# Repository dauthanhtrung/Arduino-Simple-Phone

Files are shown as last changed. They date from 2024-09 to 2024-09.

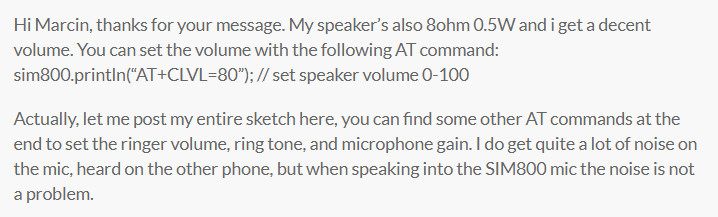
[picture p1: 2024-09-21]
DOCUMENT/79e526133139c4679d28.jpg

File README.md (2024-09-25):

# Arduino Simple Phone for Education

A mobile device capable of making calls and sending messages via the Arduino platform.

## Authors

- Facebook: [Đậu Thành Trung](https://www.facebook.com/dauthanhtrung.kma/)

- Email: dauthanhtrung.kma@gmail.com
## Demo
https://www.instructables.com/Arduino-Simple-Phone-for-Education/
## 🔗 Contact


## Screenshots

App Screenshot
App Screenshot
App Screenshot

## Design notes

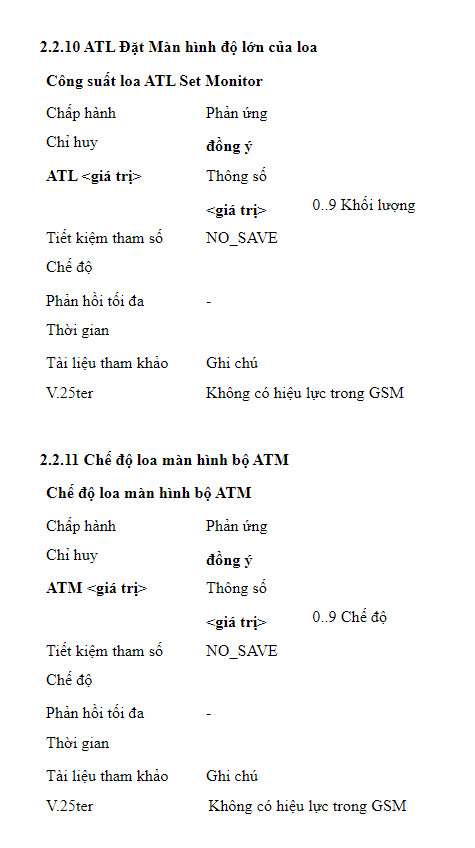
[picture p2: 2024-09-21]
DOCUMENT/1891669b77b182efdba0.jpg

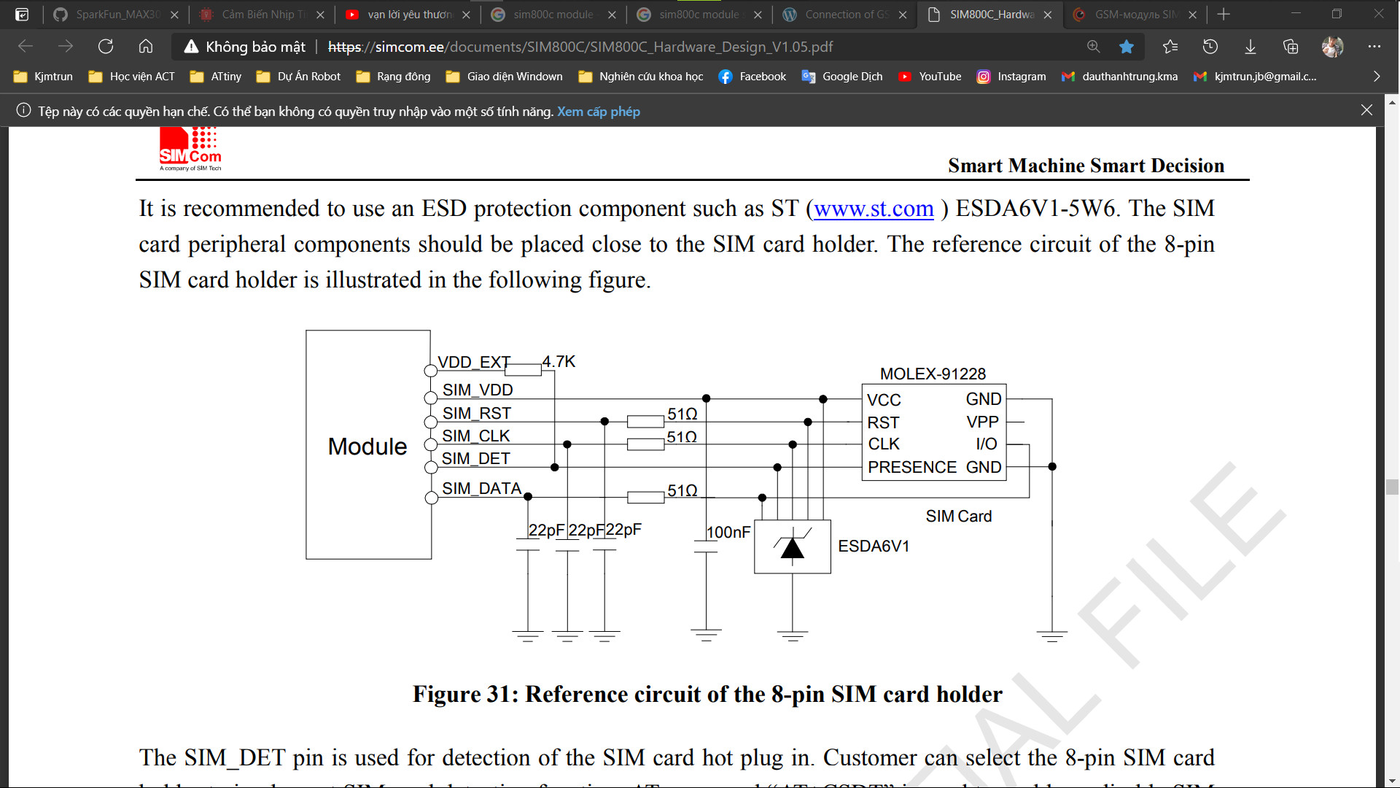
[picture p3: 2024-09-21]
DOCUMENT/d0e18e2aa135546b0d24.jpg

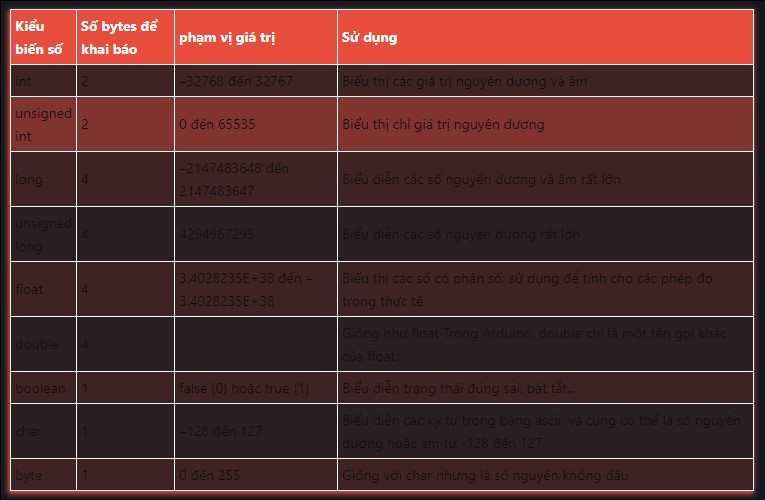
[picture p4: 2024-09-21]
DOCUMENT/KIỂU DỮ LIỆU.jpg

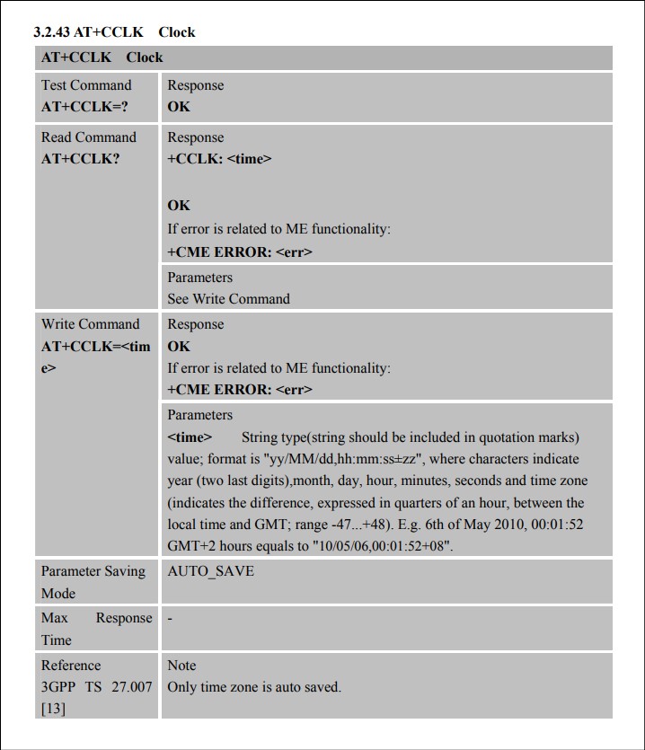
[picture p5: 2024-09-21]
DOCUMENT/Screenshot 2021-08-05 191245.jpg

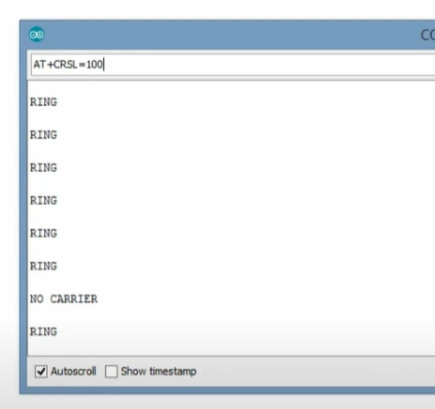
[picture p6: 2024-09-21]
DOCUMENT/7be02316343cc162982d.jpg

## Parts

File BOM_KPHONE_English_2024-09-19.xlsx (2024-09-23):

DANH SÁCH LINH KIỆN - BOMLIST
Bill of Materials for Project [KPHONE.PrjPcb] (No PCB Document Selected)
KMA ELECTRICAL |  |  | Project Name: | KPHONE.PrjPcb | Report Date: | 19/9/2024
 |  |  | Author: | Thành Trung |  | 01:40 PM
STT | Description | Comment | Footprint | Designator | Quantity | Note
1 | Antenna SMA | Antenna SMA | ANTEN SMA FEMALE | A2 | 1
2 | Button 2 pin | RESET | BUTTON-SMD-2P-3x6x2.5MM | B1 | 1
3 | Button 4 pin | Button | BUTTON-SMD-4P-6X6X5MM | B2, B3, B4, B5, B6, B7, B8, B9, B10, B11, B12, B13, B14, B15, B16, B17 | 16
4 | Buzzer | Buzzer | BUZZER_9055 | BZ1 | 1
5 | Capacitor SMD | 10uF/0805 | CAP-0805 | C1, C6, C17 | 3
6 | Capacitor SMD | 100nF/0603 | CAP-0603 | C2, C3, C4, C5, C8, C14 | 6
7 | Capacitor SMD | 0.1uF/0603 | CAP-0603 | C7, C18 | 2
8 | Capacitor SMD | 22uF/1206 | CAP-1206 | C9, C11 | 2
9 | Capacitor Pol Alumium SMD | 100uF/6.3X5.4 | CAPP-SMD-ALU-6.3X5.4MM-D | C10, C16 | 2
10 | Capacitor SMD | 22pF/0603 | CAP-0603 | C12, C13, C19, C20, C21, C22, C23, C24 | 8
11 | Capacitor SMD | 100nF | CAP-0603 | C15 | 1
12 | Diode Schottky | SS34 | DIODE-SMD-DO-214AC | D1 | 1
13 | USB 5P | USB | USB-FEMALE-MICRO-DIP | J1 | 1
14 | Header 2P | 2P | XH2.54-2P-R | J2 | 1
15 | Jump 4P | 4P | JUMP-2.54-MALE-4P-NB | J3, J4 | 2
16 | Socket Sim | Socket MicroSIM | SOCKET-MICRO-SIM-6P | J5 | 1
17 | Inductor SMD | 22uH/0603 | INDUCTOR-SMD-0630 | L1 | 1
18 | LCD Module Display Nokia 5110 SMD PCB | LCD NOKIA 5110 | LCD NOKIA 5110-SMD | LCD1 | 1
19 | Led SMD | BLUE/0603 | LED-0603-BLUE | LED1, LED4, LED6 | 3
20 | Led SMD | RED/0603 | LED-0603-RED | LED2, LED3, LED5 | 3
21 | Led SMD | WHITE/0603 | LED-0603-WHITE | LED7, LED8, LED9, LED10 | 4
22 | Led DIP | WHITE/5MM | LED-5MM-RED-R | LED11 | 1
23 | Module SIM800C PCB | SIM800C | SIM800C | M1 | 1
24 | Microphone MIC | Micro | MICRO-DIP-4.5X2.2-P2.0 | MIC1 | 1
25 | Transistor NPN | NPN | TRANSISTOR-SOT-23-BCE | Q1, Q2, Q3 | 3
26 | Resistor SMD | 100R | RES-0603 | R1 | 1
27 | Resistor SMD | 1K/0603 | RES-0603 | R2, R3, R4, R11, R17, R18, R29, R30, R31 | 9
28 | Resistor SMD | 1K2/0603 | RES-0603 | R5 | 1
29 | Resistor SMD | 0R/0805 | RES-0805 | R6, R7, R8, R13, R14 | 5
30 | Resistor SMD | 1K5/0603 | RES-0603 | R9 | 1
31 | Resistor SMD | 3K/0603 | RES-0603 | R10 | 1
32 | Resistor SMD | 4K7/0603 | RES-0603 | R12, R24 | 2
33 | Resistor SMD | NC | RES-0603 | R15 | 1
34 | Resistor SMD | 0R/0603 | RES-0603 | R16, R19, R20, R26 | 4
35 | Resistor SMD | 100R/0603 | RES-0603 | R21, R22, R23, R25, R27, R28 | 6
36 | Speaker | 4R/8W | SPEAKER 9X22MM | SPK1 | 1
37 | Switch SK-12D07 | Switch | SWITCH-3PIN-R | SW1 | 1
38 | IC DW01 SOT23-6 | DW01 | SOT-23-6 | U1 | 1
39 | IC TP4056 3.7V SOP-8 | TP4056 | TP4056 | U2 | 1
40 | IC FS8205A Dual N-Mosfet TSSOP-8 | FS8205A | FS8205A | U3 | 1
41 | IC ATmega328P IC MCU 8BIT 32KB FLASH 32P | ATmega328P | TQFP-32 | U4 | 1
42 | IC MT3608 DC-DC Converters 1.2MHz SOT-23-6 | MT3608 | SOT-23-6 | U5 | 1
43 | IC CH340C USB to TTL 2Mbps USB2.0 SOP-16 | CH340C | SOP-16 | U6 | 1
44 | Crystal 2P | 16MHz | CRYSTAL-SMD-5032-2P | X1 | 1

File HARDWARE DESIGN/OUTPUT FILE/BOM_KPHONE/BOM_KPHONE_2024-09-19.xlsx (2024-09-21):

DANH SÁCH LINH KIỆN - BOMLIST
Bill of Materials for Project [KPHONE.PrjPcb] (No PCB Document Selected)
KMA ELECTRICAL |  |  | Project Name: | KPHONE.PrjPcb | Report Date: | 19/9/2024
 |  |  | Author: | Thành Trung |  | 01:40 PM
STT | Description | Comment | Footprint | Designator | Quantity | Note
1 | Antenna SMA | Antenna SMA | ANTEN SMA FEMALE | A2 | 1
2 | Nút nhấn 2 chân | RESET | BUTTON-SMD-2P-3x6x2.5MM | B1 | 1
3 | Nút nhấn 4 chân | Button | BUTTON-SMD-4P-6X6X5MM | B2, B3, B4, B5, B6, B7, B8, B9, B10, B11, B12, B13, B14, B15, B16, B17 | 16
4 | Còi chip | Buzzer | BUZZER_9055 | BZ1 | 1
5 | Tụ dán | 10uF/0805 | CAP-0805 | C1, C6, C17 | 3
6 | Tụ dán | 100nF/0603 | CAP-0603 | C2, C3, C4, C5, C8, C14 | 6
7 | Tụ dán | 0.1uF/0603 | CAP-0603 | C7, C18 | 2
8 | Tụ dán | 22uF/1206 | CAP-1206 | C9, C11 | 2
9 | Tụ hoá dán | 100uF/6.3X5.4 | CAPP-SMD-ALU-6.3X5.4MM-D | C10, C16 | 2
10 | Tụ dán | 22pF/0603 | CAP-0603 | C12, C13, C19, C20, C21, C22, C23, C24 | 8
11 | Tụ dán | 100nF | CAP-0603 | C15 | 1
12 | Diode Schottky | SS34 | DIODE-SMD-DO-214AC | D1 | 1
13 | Cổng USB 5P | USB | USB-FEMALE-MICRO-DIP | J1 | 1
14 | Header 2P | 2P | XH2.54-2P-R | J2 | 1
15 | Jump 4P | 4P | JUMP-2.54-MALE-4P-NB | J3, J4 | 2
16 | Khe cắm Sim | Socket MicroSIM | SOCKET-MICRO-SIM-6P | J5 | 1
17 | Cuộn cảm dán | 22uH/0603 | INDUCTOR-SMD-0630 | L1 | 1
18 | LCD Module màn hình Nokia 5110 SMD PCB | LCD NOKIA 5110 | LCD NOKIA 5110-SMD | LCD1 | 1
19 | Led dán | BLUE/0603 | LED-0603-BLUE | LED1, LED4, LED6 | 3
20 | Led dán | RED/0603 | LED-0603-RED | LED2, LED3, LED5 | 3
21 | Led dán | WHITE/0603 | LED-0603-WHITE | LED7, LED8, LED9, LED10 | 4
22 | Led cắm | WHITE/5MM | LED-5MM-RED-R | LED11 | 1
23 | Module SIM800C hàn mạch PCB | SIM800C | SIM800C | M1 | 1
24 | Cảm biến âm thanh Microphone MIC | Micro | MICRO-DIP-4.5X2.2-P2.0 | MIC1 | 1
25 | Transistor NPN | NPN | TRANSISTOR-SOT-23-BCE | Q1, Q2, Q3 | 3
26 | Điện trở dán | 100R | RES-0603 | R1 | 1
27 | Điện trở dán | 1K/0603 | RES-0603 | R2, R3, R4, R11, R17, R18, R29, R30, R31 | 9
28 | Điện trở dán | 1K2/0603 | RES-0603 | R5 | 1
29 | Điện trở dán | 0R/0805 | RES-0805 | R6, R7, R8, R13, R14 | 5
30 | Điện trở dán | 1K5/0603 | RES-0603 | R9 | 1
31 | Điện trở dán | 3K/0603 | RES-0603 | R10 | 1
32 | Điện trở dán | 4K7/0603 | RES-0603 | R12, R24 | 2
33 | Điện trở dán | NC | RES-0603 | R15 | 1
34 | Điện trở dán | 0R/0603 | RES-0603 | R16, R19, R20, R26 | 4
35 | Điện trở dán | 100R/0603 | RES-0603 | R21, R22, R23, R25, R27, R28 | 6
36 | Loa | 4R/8W | SPEAKER 9X22MM | SPK1 | 1
37 | Công tắc gạt | Switch | SWITCH-3PIN-R | SW1 | 1
38 | IC DW01 Bảo vệ Pin SOT23-6 | DW01 | SOT-23-6 | U1 | 1
39 | IC TP4056 Quản lý sạc pin 3.7V SOP-8 | TP4056 | TP4056 | U2 | 1
40 | IC FS8205A Dual N-Mosfet TSSOP-8 | FS8205A | FS8205A | U3 | 1
41 | IC ATmega328P IC MCU 8BIT 32KB FLASH 32P | ATmega328P | TQFP-32 | U4 | 1
42 | IC MT3608 DC-DC Converters 1.2MHz SOT-23-6 | MT3608 | SOT-23-6 | U5 | 1
43 | IC CH340C Chuyển đổi USB to TTL 2Mbps USB2.0 SOP-16 | CH340C | SOP-16 | U6 | 1
44 | Thạch anh 2P | 16MHz | CRYSTAL-SMD-5032-2P | X1 | 1

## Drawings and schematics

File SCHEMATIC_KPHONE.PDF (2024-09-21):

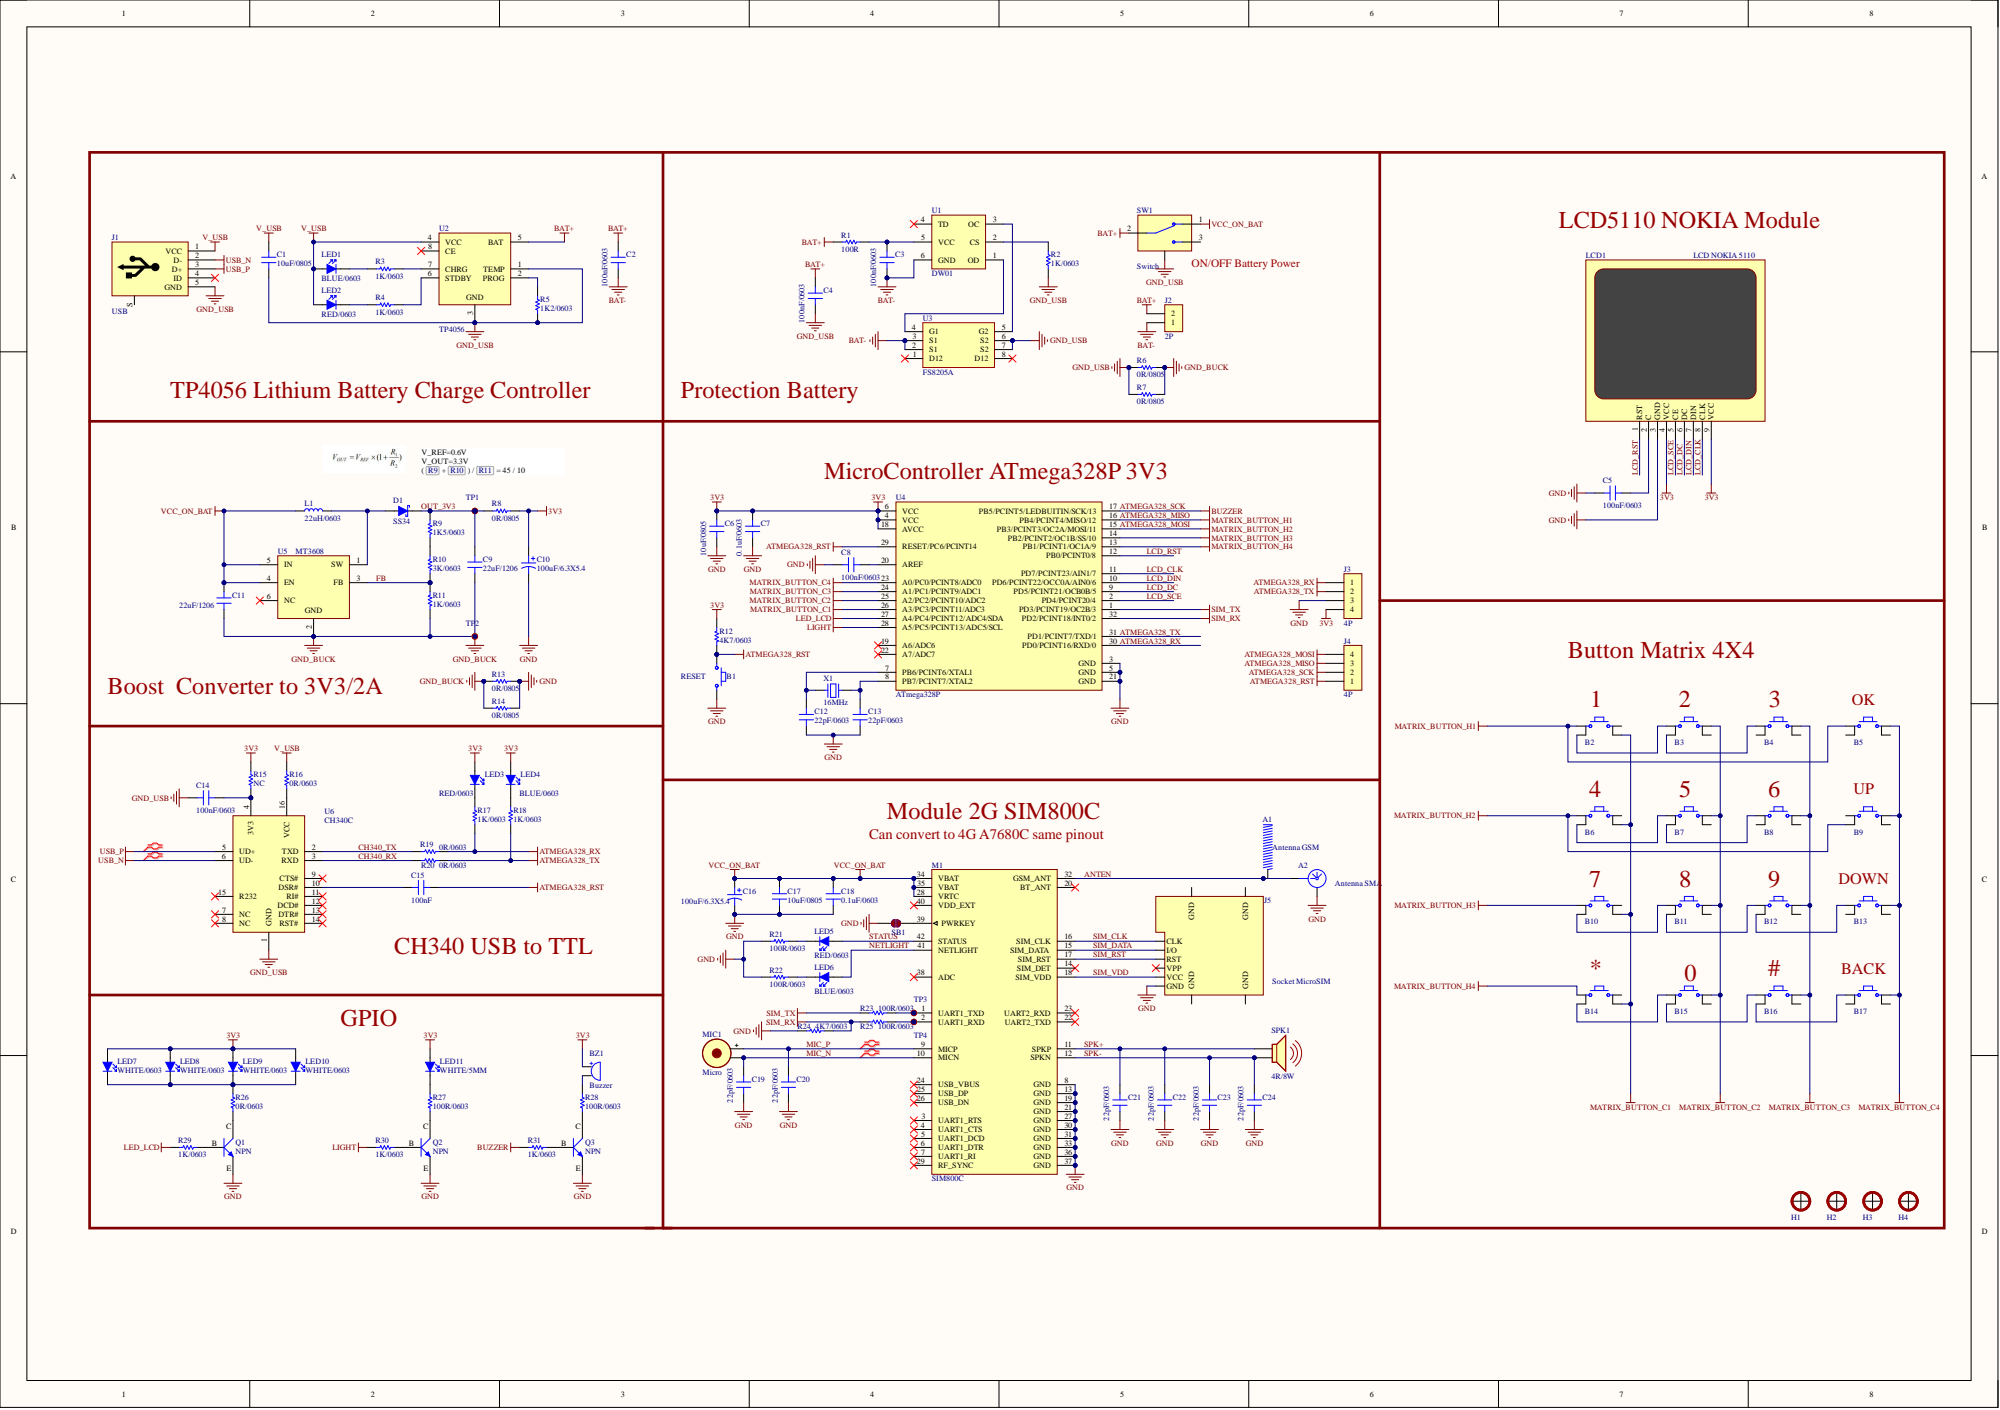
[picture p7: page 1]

ON/OFF Battery Power

Can convert to 4G A7680C same pinout

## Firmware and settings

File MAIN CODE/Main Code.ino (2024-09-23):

//****************************************//
//  Code by Dau Thanh Trung
//  Hoc Vien Ki Thuat Mat Ma
//  Phone: 0868242509
//  Gmail: dauthanhtrung.kma@gmail.com
//***************************************//
#include <SPI.h>
#include <Adafruit_GFX.h>
#include <Adafruit_PCD8544.h>	//Lcd Library
#include <String.h>
#include <SoftwareSerial.h>
#include <Keypad.h> 		//Keypad library
// #include <TimerOne.h>

//********************************************************************************************//

SoftwareSerial PHONE(3,2);// Connect with SIM module (Tx, Rx);
Adafruit_PCD8544 display = Adafruit_PCD8544(7, 6, 5, 4, 8); // LCD Nokia 5110 connect pin with Arduino
                                          //SCLK,DIN,DC,SCE,RST

// keyboard diagram
const byte ROWS = 4; 
const byte COLS = 4; 
char hexaKeys[ROWS][COLS] = {
  {'1', '2', '3', 'A'},
  {'4', '5', '6', 'B'},
  {'7', '8', '9', 'C'},
  {'*', '0', '#', 'D'}
};
/* A-OK; B-UP; C-DOWN; D-BACK*/

byte rowPins[ROWS] = {12, 11, 10, 9};  //Rows
byte colPins[COLS] = {A3, A2, A1, A0}; //Cols
Keypad key = Keypad(makeKeymap(hexaKeys), rowPins, colPins, ROWS, COLS); // Init Keypad

//********************************************************************************************//

boolean backlight = true;

unsigned char menu_item = 1;
unsigned char message_item = 1;
unsigned char page = 0;
int count=0;

//********************************************************************************************//
// Variables used
String number="";
String NUMBER=""; // number phone
String msg="";
String instr="";
String str_sms="";
String str_sms_2="";
String str_sms_3="";
String str1="";
String sms="";

String dd="";
String mm="";
String yy="";
String hh="";
String min="";
String time="";
String time_now="";


int ring=0;
int i=0,temp=0;
int sms_flag=0;
char sms_num[3];
int rec_read=0;
int temp1=0;

String ch="1,.?!@abc2def3ghi4jkl5mno6pqrs7tuv8wxyz90*# "; // Code for message

unsigned long real_time;  
unsigned char t=0;
unsigned char contrast=50;
char myKey;

//********************************************************************************************//
#define LIGHT A5	//Connect pin
#define BUZZER 13
#define LED_LCD A4


static const unsigned char PROGMEM tim[] = // Phone wave icon
{ 0x00,0x6C,0xFE,0xFE,0x7C,0x38,0x10,0x00};
// 'lock', 84x48px
const unsigned char LOCK [] PROGMEM = { // Lock icon
	0x00, 0x00, 0x00, 0x00, 0x00, 0x00, 0x00, 0x00, 0x00, 0x00, 0x00, 0x00, 0x00, 0x00, 0x00, 0x00, 
	0x00, 0x00, 0x00, 0x00, 0x00, 0x00, 0x00, 0x00, 0x00, 0x00, 0x00, 0x00, 0x00, 0x00, 0x00, 0x00, 
	0x00, 0x00, 0x00, 0x00, 0x00, 0x00, 0x00, 0x00, 0x00, 0x00, 0x00, 0x00, 0x00, 0x00, 0x00, 0x00, 
	0x00, 0x00, 0x00, 0x00, 0x00, 0x00, 0x00, 0x00, 0x00, 0x00, 0x00, 0x00, 0x00, 0x00, 0x00, 0x00, 
	0x00, 0x00, 0x00, 0x00, 0x00, 0x00, 0x07, 0xc0, 0x00, 0x00, 0x00, 0x00, 0x00, 0x00, 0x00, 0x00, 
	0x00, 0x1f, 0xf0, 0x00, 0x00, 0x00, 0x00, 0x00, 0x00, 0x00, 0x00, 0x00, 0x3f, 0xfc, 0x00, 0x00, 
	0x00, 0x00, 0x00, 0x00, 0x00, 0x00, 0x00, 0x7f, 0xfe, 0x00, 0x00, 0x00, 0x00, 0x00, 0x00, 0x00, 
	0x00, 0x00, 0xf8, 0x3e, 0x00, 0x00, 0x00, 0x00, 0x00, 0x00, 0x00, 0x00, 0x01, 0xf0, 0x0f, 0x00, 
	0x00, 0x00, 0x00, 0x00, 0x00, 0x00, 0x00, 0x01, 0xe0, 0x07, 0x80, 0x00, 0x00, 0x00, 0x00, 0x00, 
	0x00, 0x00, 0x03, 0xc0, 0x07, 0x80, 0x00, 0x00, 0x00, 0x00, 0x00, 0x00, 0x00, 0x03, 0xc0, 0x03, 
	0x80, 0x00, 0x00, 0x00, 0x00, 0x00, 0x00, 0x00, 0x03, 0x80, 0x03, 0x80, 0x00, 0x00, 0x00, 0x00, 
	0x00, 0x00, 0x00, 0x03, 0x80, 0x03, 0xc0, 0x00, 0x00, 0x00, 0x00, 0x00, 0x00, 0x00, 0x03, 0x80, 
	0x03, 0xc0, 0x00, 0x00, 0x00, 0x00, 0x00, 0x00, 0x00, 0x03, 0x80, 0x03, 0xc0, 0x00, 0x00, 0x00, 
	0x00, 0x00, 0x00, 0x00, 0x03, 0x80, 0x03, 0xc0, 0x00, 0x00, 0x00, 0x00, 0x00, 0x00, 0x00, 0x0f, 
	0xff, 0xff, 0xe0, 0x00, 0x00, 0x00, 0x00, 0x00, 0x00, 0x00, 0x1f, 0xff, 0xff, 0xf0, 0x00, 0x00, 
	0x00, 0x00, 0x00, 0x00, 0x00, 0x1f, 0xff, 0xff, 0xf0, 0x00, 0x00, 0x00, 0x00, 0x00, 0x00, 0x00, 
	0x1f, 0xff, 0xff, 0xf0, 0x00, 0x00, 0x00, 0x00, 0x00, 0x00, 0x00, 0x1f, 0xfc, 0x7f, 0xf0, 0x00, 
	0x00, 0x00, 0x00, 0x00, 0x00, 0x00, 0x1f, 0xf8, 0x3f, 0xf0, 0x00, 0x00, 0x00, 0x00, 0x00, 0x00, 
	0x00, 0x1f, 0xf0, 0x1f, 0xf0, 0x00, 0x00, 0x00, 0x00, 0x00, 0x00, 0x00, 0x1f, 0xf0, 0x1f, 0xf0, 
	0x00, 0x00, 0x00, 0x00, 0x00, 0x00, 0x00, 0x1f, 0xf0, 0x1f, 0xf0, 0x00, 0x00, 0x00, 0x00, 0x00, 
	0x00, 0x00, 0x1f, 0xf8, 0x1f, 0xf0, 0x00, 0x00, 0x00, 0x00, 0x00, 0x00, 0x00, 0x1f, 0xf8, 0x3f, 
	0xf0, 0x00, 0x00, 0x00, 0x00, 0x00, 0x00, 0x00, 0x1f, 0xfc, 0x7f, 0xf0, 0x00, 0x00, 0x00, 0x00, 
	0x00, 0x00, 0x00, 0x1f, 0xfc, 0x3f, 0xf0, 0x00, 0x00, 0x00, 0x00, 0x00, 0x00, 0x00, 0x1f, 0xf8, 
	0x3f, 0xf0, 0x00, 0x00, 0x00, 0x00, 0x00, 0x00, 0x00, 0x1f, 0xf8, 0x3f, 0xf0, 0x00, 0x00, 0x00, 
	0x00, 0x00, 0x00, 0x00, 0x1f, 0xf8, 0x3f, 0xf0, 0x00, 0x00, 0x00, 0x00, 0x00, 0x00, 0x00, 0x1f, 
	0xf8, 0x1f, 0xf0, 0x00, 0x00, 0x00, 0x00, 0x00, 0x00, 0x00, 0x1f, 0xf0, 0x1f, 0xf0, 0x00, 0x00, 
	0x00, 0x00, 0x00, 0x00, 0x00, 0x1f, 0xff, 0xff, 0xf0, 0x00, 0x00, 0x00, 0x00, 0x00, 0x00, 0x00, 
	0x1f, 0xff, 0xff, 0xf0, 0x00, 0x00, 0x00, 0x00, 0x00, 0x00, 0x00, 0x0f, 0xff, 0xff, 0xf0, 0x00, 
	0x00, 0x00, 0x00, 0x00, 0x00, 0x00, 0x0f, 0xff, 0xff, 0xe0, 0x00, 0x00, 0x00, 0x00, 0x00, 0x00, 
	0x00, 0x00, 0x00, 0x00, 0x00, 0x00, 0x00, 0x00, 0x00, 0x00, 0x00, 0x00, 0x00, 0x00, 0x00, 0x00, 
	0x00, 0x00, 0x00, 0x00, 0x00, 0x00, 0x00, 0x00, 0x00, 0x00, 0x00, 0x00, 0x00, 0x00, 0x00, 0x00, 
	0x00, 0x00, 0x00, 0x00, 0x00, 0x00, 0x00, 0x00, 0x00, 0x00, 0x00, 0x00, 0x00, 0x00, 0x00, 0x00, 
	0x00, 0x00, 0x00, 0x00, 0x00, 0x00, 0x00, 0x00, 0x00, 0x00, 0x00, 0x00, 0x00, 0x00, 0x00, 0x00
};


static const unsigned char PROGMEM viettel[] = // Network provider icon
{ B00000000, B00000000,
  B00000000, B00000000,
  B00000001, B00000000,
  B00000101, B00000000,
  B00010101, B00000000,
  B01010101, B00000000,
  B01010101, B00000000,
  B01010101, B00000000,
  B00000000, B00000000,
  B00000000, B00000000,
  B00000000, B00000000,
  B00000000, B00000000,
  B00000000, B00000000,
  B00000000, B00000000,
  B00000000, B00000000,
  B00000000, B00000000 };
static const unsigned char PROGMEM battery_icon[] =  // Battery icon
{ B00000000, B00000000,
  B01111111, B11000000,
  B01000000, B01000000,
  B11010101, B01000000,
  B11010101, B01000000,
  B11010101, B01000000,
  B01000000, B01000000,
  B01111111, B11000000,
  B00000000, B00000000,
  B00000000, B00000000,
  B00000000, B00000000,
  B00000000, B00000000,
  B00000000, B00000000,
  B00000000, B00000000,
  B00000000, B00000000,
  B00000000, B00000000 };

static const unsigned char PROGMEM message_icon[] =  // Message icon
{ B11111111, B11111000,
  B10100000, B00101000,
  B10010000, B01001000,
  B10001000, B10001000,
  B10000101, B00001000,
  B10000010, B00001000,
  B10000000, B00001000,
  B11111111, B11111000,
  B00000000, B00000000,
  B00000000, B00000000,
  B00000000, B00000000,
  B00000000, B00000000,
  B00000000, B00000000,
  B00000000, B00000000,
  B00000000, B00000000,
  B00000000, B00000000 };

void setup() {
  pinMode(LED_LCD,OUTPUT);  //Backlight for LCD
  pinMode(LIGHT,OUTPUT);    //Light
  pinMode(BUZZER,OUTPUT);   //Buzzer

  digitalWrite(LED_LCD,LOW);
  digitalWrite(LIGHT,LOW);
  digitalWrite(BUZZER,LOW);
  // Timer1.initialize(1000000); //Init interrupt
  // Timer1.attachInterrupt(GetTime);
  real_time = millis();
  // Serial.begin(9600);
  //Init LCD
  display.begin();      
  // display.setContrast(50); //Set contrast to 50
  display.setContrast(contrast);
  display.display();
  display.clearDisplay(); 
  display.display(); 
  //Init SIM module
  PHONE.begin(9600);
  gsm_init();
  
  // delay(2000);
}

void loop() { //Main program
  if( (millis() - real_time) >10000 ){ // get time from network
    real_time = millis();
    GetTime();
  }
  serialEvent(); // Check message and calling
  myKey = key.getKey();//Check button keypad
  drawMenu(); // Main Home
  
  // Handling incoming call and message events
  if(ring == 1){ // Incoming call detected
    while(ring==1)
    {
     
      page_7();
      ring=0;
      GetTime();
      // page=0;
      // break;
    }
    instr=""; i=0;// reset state
    GetTime();
    delay(500);
  }
  //*****************************Get message********************************//
  // if(sms_flag==1){
  //   while(sms_flag==1)
  //   {
  //     display.clearDisplay();
  //     str_sms=instr;
  //     int loc=instr.indexOf("+CMT: \"");
  //     number=instr.substring(loc+7,loc+19); // Split phone number

  //     int L1=str_sms.indexOf("+CMT: \"");
  //     int L2 = str_sms.length();
  //     str_sms_2=str_sms.substring(L1,L2); // Split content

  //     int L3=str_sms_2.indexOf("\"\r\n");
  //     int L4=str_sms_2.length();
  //     str_sms_3=str_sms_2.substring(L3+3,L4); // Extract message content
  //     String sms = str_sms_3; 
  //     display.setCursor(0,10);
  //     display.print(number); // Get phone number
  //     display.setCursor(0,20);
  //     display.print("<");
  //     display.print(str_sms_3); // New message
  //     display.print("Noi dung: "); // New message
  //     display.print(">");
  //     display.display();
  //     delay(5000);
  //     page_9();
  //     // instr=""; // Reset state
  //     str_sms="";
  //     str_sms_2="";
  //     str_sms_3="";
  //     sms="";number="";
  //     sms_flag=0;
  //     page=0;
  //     GetTime();
  //   }
  //   delay(200);
    
  // }
 

  //Lock screen by button '0'
  if (myKey=='0')
  {
    if (page == 0){
      page=99;
    }
    else if (page == 99){
      page=0;
    }
  }
  // Change menu and variable
  //Button OK
  if (myKey=='A')
  {
    if (page == 1 && menu_item==3) 
    {
      if (backlight) 
      {
        backlight = false;
        digitalWrite(LIGHT,HIGH);
      }
      else 
      {
        backlight = true; 
        digitalWrite(LIGHT,LOW);
        
      }
    }

    if(page == 1 && menu_item ==2)
    {
      page=3;
    }
    else if (page == 1 && menu_item==1)
    {
      page=2;
    }
    else if (page == 0 )
    {
      page=1;
    }
    else if (page == 8 && temp1 == 1 )
    {
      DocTinNhan();
    }
    else if (page == 4 && message_item )
    {
      page_5();
    }
  }
  //Button up
  if (myKey=='B')
  {
    if (page == 0){
      contrast++;
      if(contrast>50) contrast=25;
      display.setContrast(contrast);
      display.display();
    }
    else if (page == 1 ) 
    {
      menu_item--;
      if (menu_item==0) menu_item=3;
    }
    else if(page ==3)
    {
      temp++;
    }
    else if(page == 4 ) 
    {
      message_item--;
      if (message_item==0) message_item=3;
    }
  }

//Button down
  if (myKey=='C')
  {
    if (page == 0){
      contrast--;
      if(contrast<25) contrast=50;
      display.setContrast(contrast);
      display.display();
    }
    else if (page == 1)
    {
      menu_item++;
      if (menu_item==4) menu_item=1;      
    }
    else if(page ==3)
    {
      temp--;
    }
    else if(page == 4 )
    {
      message_item++;
      if (message_item==4) message_item=1;
    }
  }
  

   //Button Back
   if (myKey=='D') //BACK
   { 
    if (page == 1 )
    {
      page=0;
    }
    else if (page == 2) 
    {
      page=1;
     }

    else if (page == 4) 
    {
      page=3;
    }
    else if (page == 0) 
    {
      page=8;
    }
    else if (page == 8) 
    {
      page=0;
    }

   }
   
}
void NhapSDT()
{
  count=0;
  NUMBER="";
  while(1) // true
  {
    char myKey = key.getKey();
    display.setTextSize(1);
    display.setTextColor(BLACK, WHITE);

    if(myKey=='1')
    {
      display.setCursor((count*6)+12, 25);
      display.print(myKey);
      NUMBER+=myKey;
      count++;
    }
    if(myKey=='2')
    {
      display.setCursor((count*6)+12, 25);
      display.print(myKey);
      NUMBER+=myKey;
      count++;
    }
    if(myKey=='3')
    {
      display.setCursor((count*6)+12, 25);
      display.print(myKey);
      NUMBER+=myKey;
      count++;
    }
    if(myKey=='4')
    {
      display.setCursor((count*6)+12, 25);
      display.print(myKey);
      NUMBER+=myKey;
      count++;
    }
    if(myKey=='5')
    {
      display.setCursor((count*6)+12, 25);
      display.print(myKey);
      NUMBER+=myKey;
      count++;
    }
    if(myKey=='6')
    {
      display.setCursor((count*6)+12, 25);
      display.print(myKey);
      NUMBER+=myKey;
      count++;
    }
    if(myKey=='7')
    {
      display.setCursor((count*6)+12, 25);
      display.print(myKey);
      NUMBER+=myKey;
      count++;
    }
    if(myKey=='8')
    {
      display.setCursor((count*6)+12, 25);
      display.print(myKey);
      NUMBER+=myKey;
      count++;
    }
    if(myKey=='9')
    {
      display.setCursor((count*6)+12, 25);
      display.print(myKey);
      NUMBER+=myKey;
      count++;
    }
    if(myKey=='0')
    {
      display.setCursor((count*6)+12, 25);
      display.print(myKey);
      NUMBER+=myKey;
      count++;
    }

    if(myKey=='A' && page == 2)// call button handle
    {
      NUMBER.remove(0,1);
      // Call command here
      PHONE.print("ATD+ +84"); // change your country code here
      PHONE.print(NUMBER);
      PHONE.println(";");
      delay(100);
      //******************************//
      page=6; // calling
      break;
    }
    if(myKey=='A' && page == 3)// handle send message button
    {
      NUMBER.remove(0,1);
      page=4; // choose message
      break;
    }
     
    if(myKey=='D') // button Delete and back
     {
        count--;
        NUMBER.remove(count);
        display.setCursor((count*6)+12, 25);
        display.print(" ");
     }
    if(myKey=='D' && count<0)
     {
       page=1;
       count=0;
       break;
     }
    if(count==0)
    {
        display.setCursor(58, 40);
        display.print("BACK");
    }
    else 
    {
        display.setCursor(58, 40);
        display.print("XOA ");
    }
    display.display();
  }
}
//********************Enter message to send***********************//
void NhapTinNhan()
{
  int x=0,y=0,num=0;
  msg="";
  while(1)
  {
    char myKey=key.getKey();
      // Enter data
       if(myKey=='1')
       {
         num=0;
         display.setCursor(x*6,(y*10)+10);
         display.print(ch[num]);
         display.display();
         for(int i=0;i<30000;i++)
         { 
          char myKey=key.getKey();
          if(myKey=='1')
          {
           num++;
           if(num>5)
           num=0;
           display.setCursor(x*6,(y*10)+10);
           display.print(ch[num]);
           display.display();
           i=0;
           delay(20);
          } 
         }
         x++;
         if(x>13)
         {
           x=0;
           y++;
           y%=3;
         }
         msg+=ch[num];
        }

       else if(myKey=='2')
       {
         num=6;
         display.setCursor(x*6,(y*10)+10);
         display.print(ch[num]);
         display.display();
         for(int i=0;i<30000;i++)
         { 
          char myKey=key.getKey();
          if(myKey=='2')
          {
           num++;
           if(num>9)
           num=6;
           display.setCursor(x*6,(y*10)+10);
           display.print(ch[num]);
           display.display();
           i=0;
           delay(20);
          } 
         }
         x++;
         if(x>13)
         {
           x=0;
           y++;
           y%=3;
         }
         msg+=ch[num];
        }

       else if(myKey=='3')
       {
         num=10;
         display.setCursor(x*6,(y*10)+10);
         display.print(ch[num]);
         display.display();
         for(int i=0;i<30000;i++)
         { 
          char myKey=key.getKey();
          if(myKey=='3')
          {
           num++;
           if(num>13)
           num=10;
           display.setCursor(x*6,(y*10)+10);
           display.print(ch[num]);
           display.display();
           i=0;
           delay(20);
          } 
         }
         x++;
         if(x>13)
         {
           x=0;
           y++;
           y%=3;
         }
         msg+=ch[num];
        }

       else if(myKey=='4')
       {
         num=14;
         display.setCursor(x*6,(y*10)+10);
         display.print(ch[num]);
         display.display();
         for(int i=0;i<30000;i++)
         { 
          char myKey=key.getKey();
          if(myKey=='4')
          {
           num++;
           if(num>17)
           num=14;
           display.setCursor(x*6,(y*10)+10);
           display.print(ch[num]);
           display.display();
           i=0;
           delay(20);
          } 
         }
         x++;
         if(x>13)
         {
           x=0;
           y++;
           y%=3;
         }
         msg+=ch[num];
        }

      else if(myKey=='5')
       {
         num=18;
         display.setCursor(x*6,(y*10)+10);
         display.print(ch[num]);
         display.display();
         for(int i=0;i<30000;i++)
         { 
          char myKey=key.getKey();
          if(myKey=='5')
          {
           num++;
           if(num>21)
           num=18;
           display.setCursor(x*6,(y*10)+10);
           display.print(ch[num]);
           display.display();
           i=0;
           delay(20);
          } 
         }
         x++;
         if(x>13)
         {
           x=0;
           y++;
           y%=3;
         }
         msg+=ch[num];
        }

        else if(myKey=='6')
       {
         num=22;
         display.setCursor(x*6,(y*10)+10);
         display.print(ch[num]);
         display.display();
         for(int i=0;i<30000;i++)
         { 
          char myKey=key.getKey();
          if(myKey=='6')
          {
           num++;
           if(num>25)
           num=22;
           display.setCursor(x*6,(y*10)+10);
           display.print(ch[num]);
           display.display();
           i=0;
           delay(20);
          } 
         }
         x++;
         if(x>13)
         {
           x=0;
           y++;
           y%=3;
         }
         msg+=ch[num];
        }

       else if(myKey=='7')
       {
         num=26;
         display.setCursor(x*6,(y*10)+10);
         display.print(ch[num]);
         display.display();
         for(int i=0;i<30000;i++)
         { 
          char myKey=key.getKey();
          if(myKey=='7')
          {
           num++;
           if(num>30)
           num=26;
           display.setCursor(x*6,(y*10)+10);
           display.print(ch[num]);
           display.display();
           i=0;
           delay(20);
          } 
         }
         x++;
         if(x>13)
         {
           x=0;
           y++;
           y%=3;
         }
         msg+=ch[num];
        }

       else if(myKey=='8')
       {
         num=31;
         display.setCursor(x*6,(y*10)+10);
         display.print(ch[num]);
         display.display();
         for(int i=0;i<30000;i++)
         { 
          char myKey=key.getKey();
          if(myKey=='8')
          {
           num++;
           if(num>34)
           num=31;
           display.setCursor(x*6,(y*10)+10);
           display.print(ch[num]);
           display.display();
           i=0;
           delay(20);
          } 
         }
         x++;
         if(x>13)
         {
           x=0;
           y++;
           y%=3;
         }
         msg+=ch[num];
        }

       else if(myKey=='9')
       {
         num=35;
         display.setCursor(x*6,(y*10)+10);
         display.print(ch[num]);
         display.display();
         for(int i=0;i<30000;i++)
         { 
          char myKey=key.getKey();
          if(myKey=='9')
          {
           num++;
           if(num>39)
           num=35;
           display.setCursor(x*6,(y*10)+10);
           display.print(ch[num]);
           display.display();
           i=0;
           delay(20);
          } 
         }
         x++;
         if(x>13)
         {
           x=0;
           y++;
           y%=3;
         }
         msg+=ch[num];
        }

        else if(myKey=='0')
       {
         num=40;
         display.setCursor(x*6,(y*10)+10);
         display.print(ch[num]);
         display.display();
         for(int i=0;i<30000;i++)
         { 
          char myKey=key.getKey();
          if(myKey=='0')
          {
           num++;
           if(num>41)
           num=40;
           display.setCursor(x*6,(y*10)+10);
           display.print(ch[num]);
           display.display();
           i=0;
           delay(20);
          } 
         }
         x++;
         if(x>13)
         {
           x=0;
           y++;
           y%=3;
         }
         msg+=ch[num];
        }

        // Function button
        else if(myKey=='D')
        {
          x--;msg.remove(x);
          if(x<0 && y>0){
            x=13;
            y--;
          }
          if(x<0 && y==0) {
            page=3;
            break;
          }
          
          display.setCursor(x*6,(y*10)+10);
          display.print(" ");
          display.display();
        } 
        else if(myKey=='A')
        {
         // Serial.println("Gửi");
          page=5;
          break;
        } 
        else if(x==0 && y==0){
            display.setCursor(58, 40);
            display.print("BACK");
            display.display();
          }
        else if(x>0 && y>=0){
            display.setCursor(58, 40);
            display.print(" XOA");
            display.display();
          }
    }
}
//***********************Read Incoming Messages********************//
void DocTinNhan()
{
  display.clearDisplay();
  display.setCursor(0,0);
  display.print(number);
  display.setCursor(0,10);
  display.print("Please wait...");
  display.display();
  delay(2000);
  // PHONE.print("AT+CMGR=");
  // PHONE.println(sms_num);
  // PHONE.print("AT+CMGR=1<CR><LF>");delay(100); //Save message to memory

  // str_sms="Dau Thanh Trung";
  // int l1=str_sms.indexOf("\"\r\n");
  // int l2=str_sms.indexOf("OK");

  // String sms=str_sms.substring(l1+3,l2-4);

  // display.clearDisplay();
  // display.print(sms);
  display.setCursor(58, 40);
  display.print("BACK");
  display.display();
  delay(5000);
}
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

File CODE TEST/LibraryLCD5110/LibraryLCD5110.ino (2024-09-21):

#include <Adafruit_GFX.h>
#include <Adafruit_PCD8544.h>
#include <SPI.h>


Adafruit_PCD8544 display = Adafruit_PCD8544(7, 6, 5, 4, 8);

// Hardware SPI (faster, but must use certain hardware pins):
// SCK is LCD serial clock (SCLK) - this is pin 13 on Arduino Uno
// MOSI is LCD DIN - this is pin 11 on an Arduino Uno
// pin 5 - Data/Command select (D/C)
// pin 4 - LCD chip select (CS)
// pin 3 - LCD reset (RST)
// Adafruit_PCD8544 display = Adafruit_PCD8544(5, 4, 3);
// Note with hardware SPI MISO and SS pins aren't used but will still be read
// and written to during SPI transfer.  Be careful sharing these pins!


static const unsigned char PROGMEM trun[] =
{ B00000000, B00000000,
  B00000000, B00000000,
  B00000000, B00000000,
  B00000000, B00000000,
  B00001100, B01100000,
  B00011110, B11110000,
  B00011111, B11110000,
  B00011111, B11110000,
  B00001111, B11100000,
  B00000111, B11000000,
  B00000011, B10000000,
  B00000001, B00000000,
  B00000000, B00000000,
  B00000000, B00000000,
  B00000000, B00000000,
  B00000000, B00000000 };
static const unsigned char PROGMEM viettel[] =
{ B00000000, B00000000,
  B00000000, B00000000,
  B00000001, B00000000,
  B00000101, B00000000,
  B00010101, B00000000,
  B01010101, B00000000,
  B01010101, B00000000,
  B01010101, B00000000,
  B00000000, B00000000,
  B00000000, B00000000,
  B00000000, B00000000,
  B00000000, B00000000,
  B00000000, B00000000,
  B00000000, B00000000,
  B00000000, B00000000,
  B00000000, B00000000 };


void setup()   {
  Serial.begin(9600);
  display.begin();// KHỞI TẠO
  display.clearDisplay();
  display.setContrast(50); // ĐỘ TƯƠNG PHẢN
  // logo();
  // delay(500);
  display.clearDisplay();
     //display.invertDisplay(true); // đảo ngược màn hình?

}
void logo(){
      display.drawBitmap(5, 5,  trun, 16, 16, 1); // vẽ logo
      display.display();
 
}
int i=0,h,w;
void loop(){
  w= display.width();   //lấy chiều rộng
  h= display.height();  //lấy chiều cao màn hình
  display.clearDisplay();     // xóa màn hình
  // display.fillRect(0, 0, 83, 47, BLACK); // vẽ nền đen
  // display.setRotation(1);     // xoay 90 độ, chọn 1,2,3
  display.setTextSize(1);     // đặt kích cỡ
  display.setTextColor(WHITE);//chọn màu chữ BLACK hoặc WHITE
  display.setCursor(28,1);     //chọn vị trí
 display.println("MENU");//in kí tự ra màn hình

  // display.setCursor(27,10);     //chọn vị trí
  // display.println(i);//in kí tự ra màn hình
  display.drawFastHLine(0,10,83,BLACK); // vẽ nhanh đường thẳng
  //Màn hình kích thước 84x48. Nhưng bắt đầu từ 0 nên 84-1 x 48-1 ~ 83x47
  // display.drawLine(0, 0, 83, 0, BLACK); //vẽ đường (x1,y1,x2,y2,BLACK). Trong tọa độ O(x,y): x- chiều rộng=83, y- chiều cao =47
  // display.drawLine(0, 0, 0, 47, BLACK);
  // display.drawLine(0, 47, 83, 47, BLACK);
  // display.drawLine(83, 0, 83, 47, BLACK);

  // display.drawLine(3, 3, 80, 3, WHITE); //vẽ đường (x1,y1,x2,y2,WHITE). Trong tọa độ O(x,y): x- chiều rộng=80, y- chiều cao =47
  // display.drawLine(3, 3, 3, 44, WHITE);
  // display.drawLine(3, 44, 80, 44, WHITE);
  // display.drawLine(80, 3, 80, 44, WHITE);

  // display.drawTriangle(display.width()/2, display.height()/2-i,
  //                    display.width()/2-i, display.height()/2+i,
  //                    display.width()/2+i, display.height()/2+i, WHITE); //Vẽ hình tam giác: tọa độ (đỉnh, đỉnh trái, đỉnh phải,WHITE);
  /*
  Hàm vẽ hình: display.draw + hình: Rect, Circle, Triangle (Vuông, tròn, tam giác)
  Đổ màu vào hình. display.fill+ hình.(Tọa độ):
  Hình vuông: lấy tọa độ đường chéo. (x1, y1, w, h, BLACK)
        //display.drawRect(65,20,4,4,BLACK);//(Tọa độ x,y, kích thước 4x4, BLACK);
  Hình tròn: lấy tọa độ tâm. và bán kính R. (x1, y1, R, BLACK)
  Hình tam giác: lấy tọa độ 3 đỉnh. (x1, y1, x2, y2, x3, y3, BLACK)
  
  */

   display.drawRoundRect(0, 0, 83, 47, 10, BLACK);// vẽ hình bo góc (tọa độ đầu, chiều rộng, chiều dài, bo góc,BLACK)
  // display.fillTriangle(display.width()/2, display.height()/2-i,
  //                    display.width()/2-i, display.height()/2+i,
  //                    display.width()/2+i, display.height()/2+i, WHITE);

  // display.fillRect(0, 0, 83, 23, 1); // vẽ nền đen
  //display.drawCircle(w/2, h/2, 40, BLACK); // Vẽ vòng tròn, với i là kích thước
  // display.setTextSize(2);
  // display.println("KMA UNIVERSITY");
  display.display();          //bắt buộc sau mỗi lần hiển thị
  i++;
  

  delay(200);

}

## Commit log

2024-09-21 Arduino Phone
    The first commit: Arduino Simple Phone
    [BOM_KPHONE_2024-09-19.xlsx, KPHONE.PrjPcb, PCB_KPHONE-BACK.PcbDoc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]
2024-09-21 Change Gerber ZIP file
    Change Gerber ZIP file and add Readme
    [PCB_KPHONE_Copper_Signal_Bot.gbr, PCB_KPHONE_Copper_Signal_Top.gbr, PCB_KPHONE_Drawing_1.gbr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]
2024-09-23 Create BOM_KPHONE_English_2024-09-19.xlsx
    Add BOM ver English
    [BOM_KPHONE_English_2024-09-19.xlsx]
